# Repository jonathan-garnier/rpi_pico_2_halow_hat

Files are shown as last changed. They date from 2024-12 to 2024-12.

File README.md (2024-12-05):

# HaLow Hat For RPI Pico 2

This repository contains design and output files for a Wi-Fi HaLow hat board for the RPI Pico 2. The board embeds a Morse Micro [MM6108-MF08651-US](https://au.mouser.com/ProductDetail/Morse-Micro/MM6108-MF08651-US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) Wi-Fi HaLow module, as well as a temperature and humidity sensor (SHT40), battery charging circuit, three LEDs, and a QWIIC connector for any other I2C based sensors. Other Wi-Fi HaLow modules with the same form factor will also be compatible, such as the Azurewave [AW-HM593](https://www.azurewave.com/wireless-modules-11ah.html).

## Images
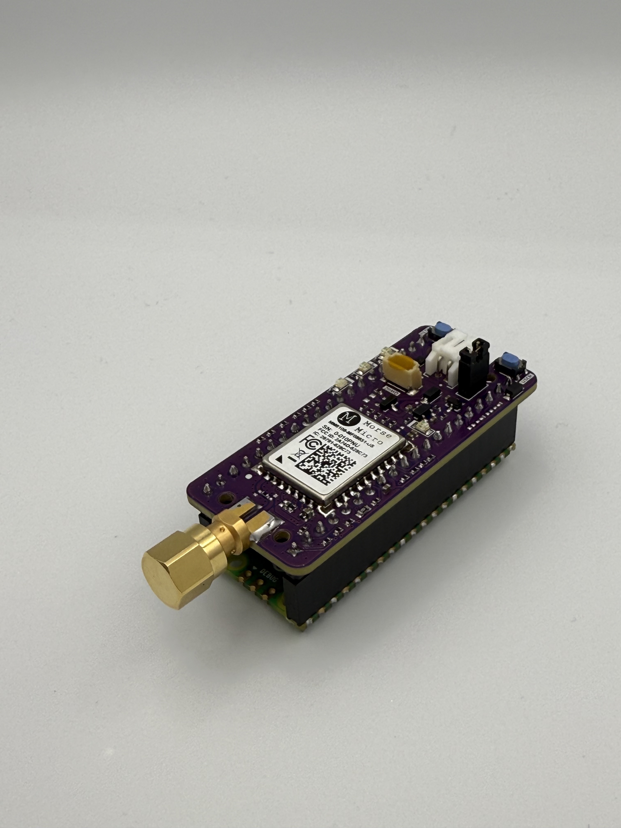
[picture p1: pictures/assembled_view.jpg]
Assembled View

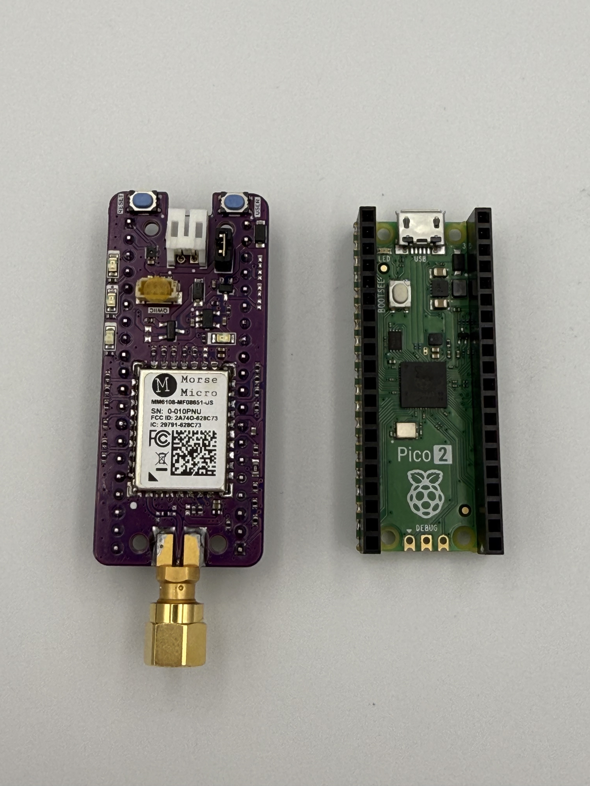
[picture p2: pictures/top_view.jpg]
Top View

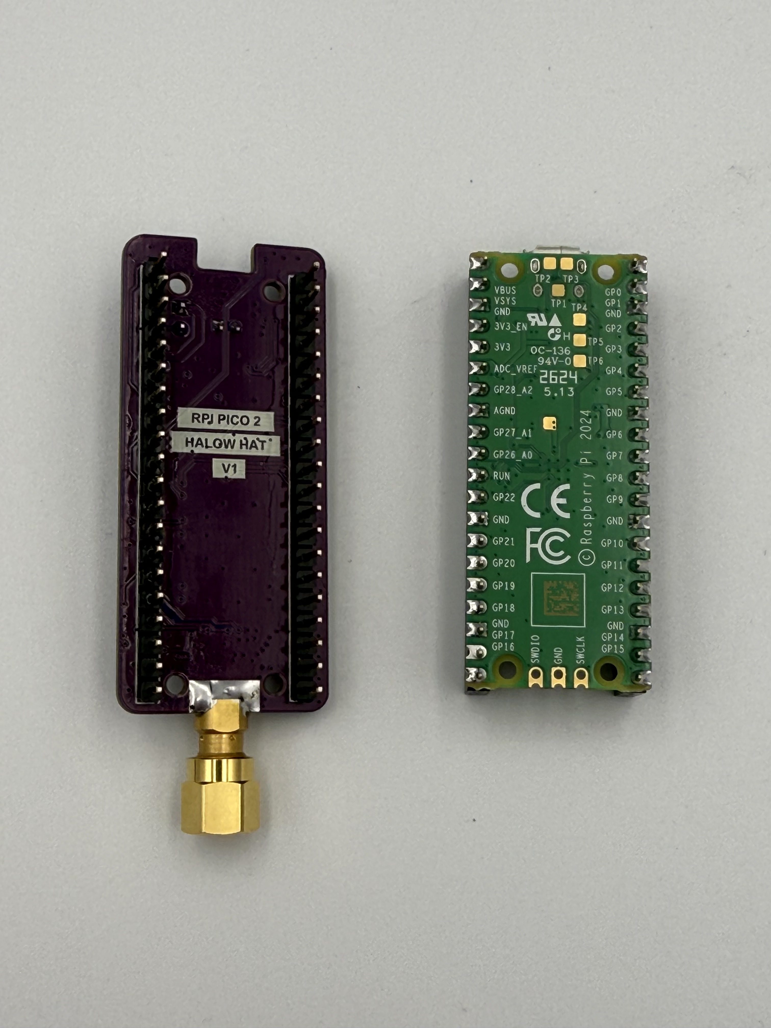
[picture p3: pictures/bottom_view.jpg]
Bottom View

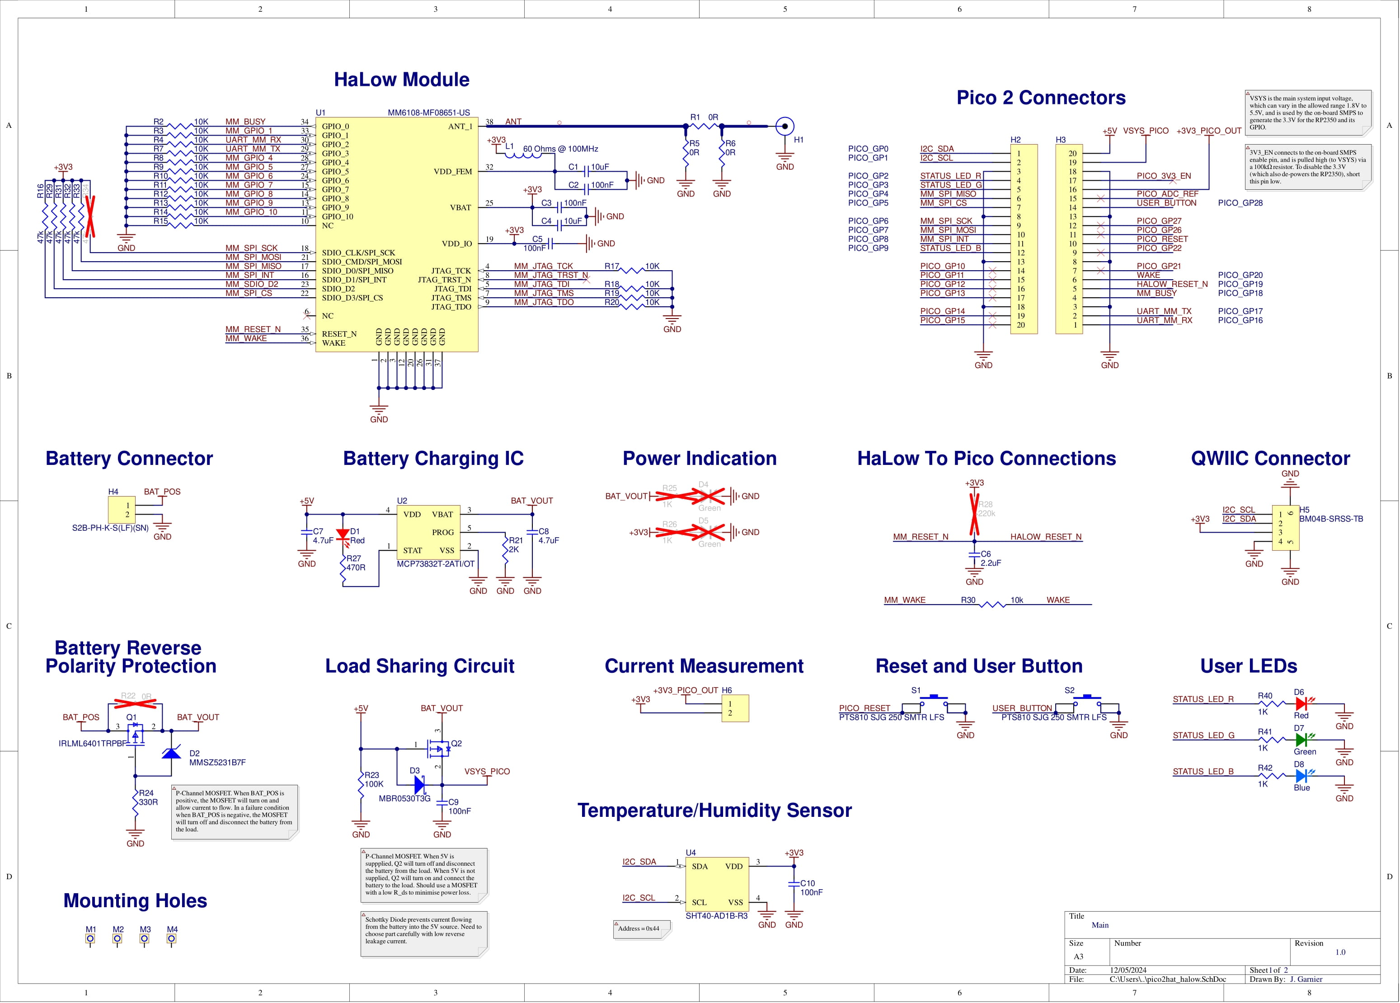
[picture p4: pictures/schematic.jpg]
Schematic


## Fabrication Files
All files needed for fabrication are in the 'Project Outputs for rpi_pico_2_hat' folder. There is a 'Fabrication' folder for gerber and other manufacturing files, and a 'Assembly Default Variant of rpi_pico_2_hat' folder which has pick and place and BOM files.

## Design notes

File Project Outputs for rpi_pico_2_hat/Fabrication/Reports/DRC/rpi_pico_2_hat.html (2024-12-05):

Altium

# Design Rule Verification Report

Date: | | 14/09/2024
Time: | | 8:18:49 AM
Elapsed Time: | | 00:00:01
Filename: | | C:\Users\JonathanGarnier\AppData\Local\Temp\Releases\Snapshot\1\rpi_pico_2_hat.PcbDoc

Warnings: | | 0
Rule Violations: | | 0

## Summary

Warnings | Count
Total | 0

Rule Violations | Count
Clearance Constraint (Gap=6mil) (InDifferentialPair('USBC')),(All) | 0
Clearance Constraint (Gap=10mil) (InNetClass('50 Ohms')),(All) | 0
Clearance Constraint (Gap=10mil) ((InPolygon)),(InNetClass('RF-Net')) | 0
Clearance Constraint (Gap=6mil) (All),(All) | 0
Short-Circuit Constraint (Allowed=No) (All),(All) | 0
Un-Routed Net Constraint ( (All) ) | 0
Un-Connected Pin Constraint ( (Disabled)(All) ) | 0
Modified Polygon (Allow modified: No), (Allow shelved: No) | 0
Width Constraint (Min=4.18mil) (Max=23.622mil) (Preferred=10.236mil) (InDifferentialPair('USBC')) | 0
Width Constraint (Min=8mil) (Max=50mil) (Preferred=8mil) (All) | 0
Width Constraint (Min=4.18mil) (Max=23.622mil) (Preferred=10mil) (InNetClass('50 OHMs')) | 0
Power Plane Connect Rule(Relief Connect )(Expansion=15.748mil) (Conductor Width=10mil) (Air Gap=7.874mil) (Entries=4) ((InComponent('J5') OR InComponent('J6') OR InComponent('J13') OR InComponent('J11') OR InComponent('J12')) OR InComponent('H3')) | 0
Power Plane Connect Rule(Relief Connect )(Expansion=20mil) (Conductor Width=10mil) (Air Gap=10mil) (Entries=4) (All) | 0
Hole Size Constraint (Min=6mil) (Max=200mil) (All) | 0
Hole To Hole Clearance (Gap=8mil) (All),(All) | 0
Minimum Solder Mask Sliver (Gap=1mil) (not InComponent('U4','U1','U5','U6','U7','U8','U9','U10')),(All) | 0
Silk To Solder Mask (Clearance=4mil) (IsPad),(All) | 0
Net Antennae (Tolerance=0mil) (All) | 0
Board Clearance Constraint (Gap=0mil) ((not OnTopSilkscreen) AND (NOT OnBottomSilkscreen) and (not OnMultiLayer) and (not InComponent('H1'))) | 0
Matched Lengths(Tolerance=1000mil) (InNetClass('DCMI')) | 0
Matched Lengths(Tolerance=50mil) (InxSignalClass('xSignals_U1_Passives_J5_MatchLengthsClass')) | 0
Matched Lengths(Tolerance=2000mil) (InNetClass('SDIO')) | 0
Matched Lengths(Tolerance=2000mil) (InNetClass('SDIO_2')) | 0
Matched Lengths(Tolerance=50mil) (InxSignalClass('xSignals_U1_Passives_J5_MatchLengthsClass_1')) | 0
Height Constraint (Min=0mil) (Max=275.591mil) (Prefered=196.85mil) (InComponentClass('POGO')) | 0
Height Constraint (Min=0mil) (Max=472.441mil) (Prefered=118.11mil) (InComponent('TP1')) | 0
Height Constraint (Min=0mil) (Max=1000mil) (Prefered=500mil) (Disabled)(All) | 0
Height Constraint (Min=0mil) (Max=157.48mil) (Prefered=118.11mil) (WithinRoom('ROOM_SOCKET')) | 0
Total | 0

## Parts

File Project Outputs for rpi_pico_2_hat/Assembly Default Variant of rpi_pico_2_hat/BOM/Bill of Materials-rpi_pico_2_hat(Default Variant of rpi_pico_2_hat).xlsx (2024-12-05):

Designator | LibRef | Quantity | Description | Footprint | Manufacturer 1 | Manufacturer Part Number 1 | Supplier 1 | Supplier Part Number 1 | Generic Allowed | Supplier Unit Price 1
H1 | JCK0001-2 | 1 | Conn, SMA Jack 50 Ohm PCB Edge Mount Gold, RoHS | SMA_EMERSON_142_0761_861 | Bel Cinch | 142-0761-861 | Farnell | 2112451 | No | 9.52
U2 | ICT0232-1 | 1 | Power Supply Support Circuit, Adjustable, 1 Channel, PDSO5 | SOT-23-OT5_N | Microchip | MCP73832T-2ATI/OT | Conrad | 1085501 |  | 2.41
U4 | ICT0108-3 | 1 | IC, Humidity Temperature Sensor 0 ~ 100% RH I²C ±1.8% RH 6 s Surface Mount | DFN140P150X59-4N | Sensirion | SHT40-AD1B-R3 | Digikey | 1649-SHT40-AD1B-R3CT-ND | No | 1.21
H5 | HDR0131-2 | 1 | Board Connector, 4 Contact(s), 1 Row(s), Male, Straight, Surface Mount Terminal | FP-BM04B-SRSS-TBT_LF_SN-MFG | JST | BM04B-SRSS-TB | Digikey | 455-BM04B-SRSS-TBCT-ND |  | 0.361
Q1 | TSR0020-1 | 1 | Small Signal Field-Effect Transistor | FP-SOT23-IPC_A | Infineon | IRLML6401TRPBF | Farnell | 1463267 |  | 0.16612
Q2 | TSR0021-1 | 1 | Small Signal Field-Effect Transistor, 1.37A I(D), 20V, 1-Element, P-Channel, Silicon, Metal-oxide Semiconductor FET | FP-419-04-IPC_A | ON Semiconductor | NTS4101PT1G | Farnell | 1453617 |  | 0.16105
D8 | DIO0018-2 | 1 | LED, Blue Clear,3.3V, SMD, 0805, RoHS | LED_0805_BLUE | Vishay Lite-On | LTST-C170TBKT | Digikey | 160-1579-1-ND | Yes | 0.1351
L1 | IND0062-6 | 1 | BEAD 60OHMS 2500MA 32 MOHM | 0402_ind | Murata | BLM15PX600SN1D | Future Electronics | 2105289 | Yes | 0.114
D7 | DIO0015-2 | 1 | LED, Green Clear,2.0V, SMD, 0805, RoHS | LED_0805_GREEN | Vishay Lite-On | LTST-C170KGKT | Digikey | 160-1414-1-ND | Yes | 0.0898
D1, D6 | DIO0016-2 | 2 | LED, Red Clear,2.0V, SMD, 0805, RoHS | LED_0805_RED | Vishay Lite-On | LTST-C170KRKT | Digikey | 160-1415-1-ND | Yes | 0.083
C1, C4 | CAP0046-13 | 2 | CAP CER 10UF 10V 20% X5R 0402 | 0402_cap | Samsung | CL05A106MP8NUB8 | Digikey | 1276-6830-1-ND | Yes | 0.0816
C7, C8 | CAP0075-12 | 2 | CAP CER 4.7UF 6.3V ±10% X5R 0402 | 0402_cap | TDK | C1005X5R0J475K050BC | Newark | 04X3211 | Yes | 0.072
R40, R41, R42 | RES0004-8 | 3 | RES SMD 1K OHM ±1% 1/10W 0402 | RESC1005X04N | Panasonic | ERJ-2RKF1001X | Future Electronics | 2103847 | Yes | 0.0464
D2 | DIO0072-1 | 1 | DIODE ZENER 5.1V 500MW SOD-123 | SOD-123FL | Diodes | MMSZ5231B7F | Newark | 12T2210 |  | 0.046
H4 | HDR0129-2 | 1 | Header for PCB; pitch 2.00mm; 2-contacts; THT; male; side entry; 100V/2A | JST-S2B-PH-K-S_V | JST | S2B-PH-K-S(LF)(SN) | Newark | 38K8066 |  | 0.039
C2, C3, C5, C9, C10 | CAP0068-11 | 5 | CAP CER 100NF 50V ±10% X7R 0402 | 0402_cap | TDK | C1005X7R1H104K050BE | Farnell | 3416071 | Yes | 0.03386
R2, R3, R4, R7, R8, R9, R10, R11, R12, R13, R14, R15, R17, R18, R19, R20 | RES0002-8 | 16 | RES SMD 10K OHM ±1% 1/10W 0402 | RESC1005X04N | Panasonic | ERJ-2RKF1002X | Farnell | 2302739 | Yes | 0.00761
C6 | CAP0086 | 1 | CAP CER 2.2UF 6.3V 20% X5R 0402 | CAPC1005X06N | Taiyo Yuden | JMK105BJ225MVF | Digikey | 587-1453-2-ND | Yes
D3 | DIO0044-2 | 1 | DIODE SCHOTTKY 30V 500MA SOD123 | SOD-123FL | ON Semiconductor | MBR0530T3G | Farnell | 2440968 | Yes
H2, H3 | HDR0128-1 | 2 | 1x20 Female Header | HDR1X20F
H6 | HDR0006-2 | 1 | Conn Straight Header 2x1 0.100" 2 POS | HDR1X2 | Oupiin | 2011-1X02G00SB-1 |  |  | Yes
M1, M2, M3, M4 | PAD0009-2 | 4 | MH NPTH 3.00mm DIA 2.75mm HOLE | MH_300_275_NPTH
R1, R5, R6 | RES0039-10 | 3 | RES SMD 0R OHM ±1% 1/16W 0402 | 0402_res | Yageo | RC0402JR-070RL | Farnell | 2421887 | Yes
R16, R29, R31, R32, R33 | RES0086-8 | 5 | RES SMD 47K OHM ±1% 1/16W 0402 | RESC1005X04N | Yageo | RC0402FR-0747KL | Farnell | 2421898 | Yes
R21 | RES0030-9 | 1 | RES SMD 2K OHM ±1% 1/16W 0402 | 0402_res | Yageo | RC0402FR-072KL | Newark | 12AC2054 | Yes
R23 | RES0023-9 | 1 | RES SMD 100K OHM ±1% 1/16W 0402 | 0402_res | Yageo | RC0402FR-07100KL | Future Electronics | 1122062 | Yes
R24 | RES0025-8 | 1 | RES SMD 330R OHM ±1% 1/16W 0402 | RESC1005X04N | Yageo | RC0402FR-07330RL | Newark | 12AC2074 | Yes
R27 | RES0084-9 | 1 | RES SMD 470R OHM ±1% 1/16W 0402 | 0402_res | Rohm | MCR01MZPF4700 |  |  | Yes
R30 | RES0124 | 1 | Res, 10K Ohm, 1/10W,+/-1%,0603 RoHS | RESC1608X06N | Rohm | MCR03EZPFX1002 | Digi-Key | 311-10.0KHRCT-ND | Yes
S1, S2 | SWH0026-1 | 2 | SWITCH TACTILE SPST-NO 0.05A 16V | SW_PTS810 | ITT C&K | PTS810SJG250SMTRLFS | Newark | 21AH2836 | No
U1 | MOD0010-3 | 1 | MM61xx-MF08 | MF04 | Morse Micro | MM61xx-MF08251

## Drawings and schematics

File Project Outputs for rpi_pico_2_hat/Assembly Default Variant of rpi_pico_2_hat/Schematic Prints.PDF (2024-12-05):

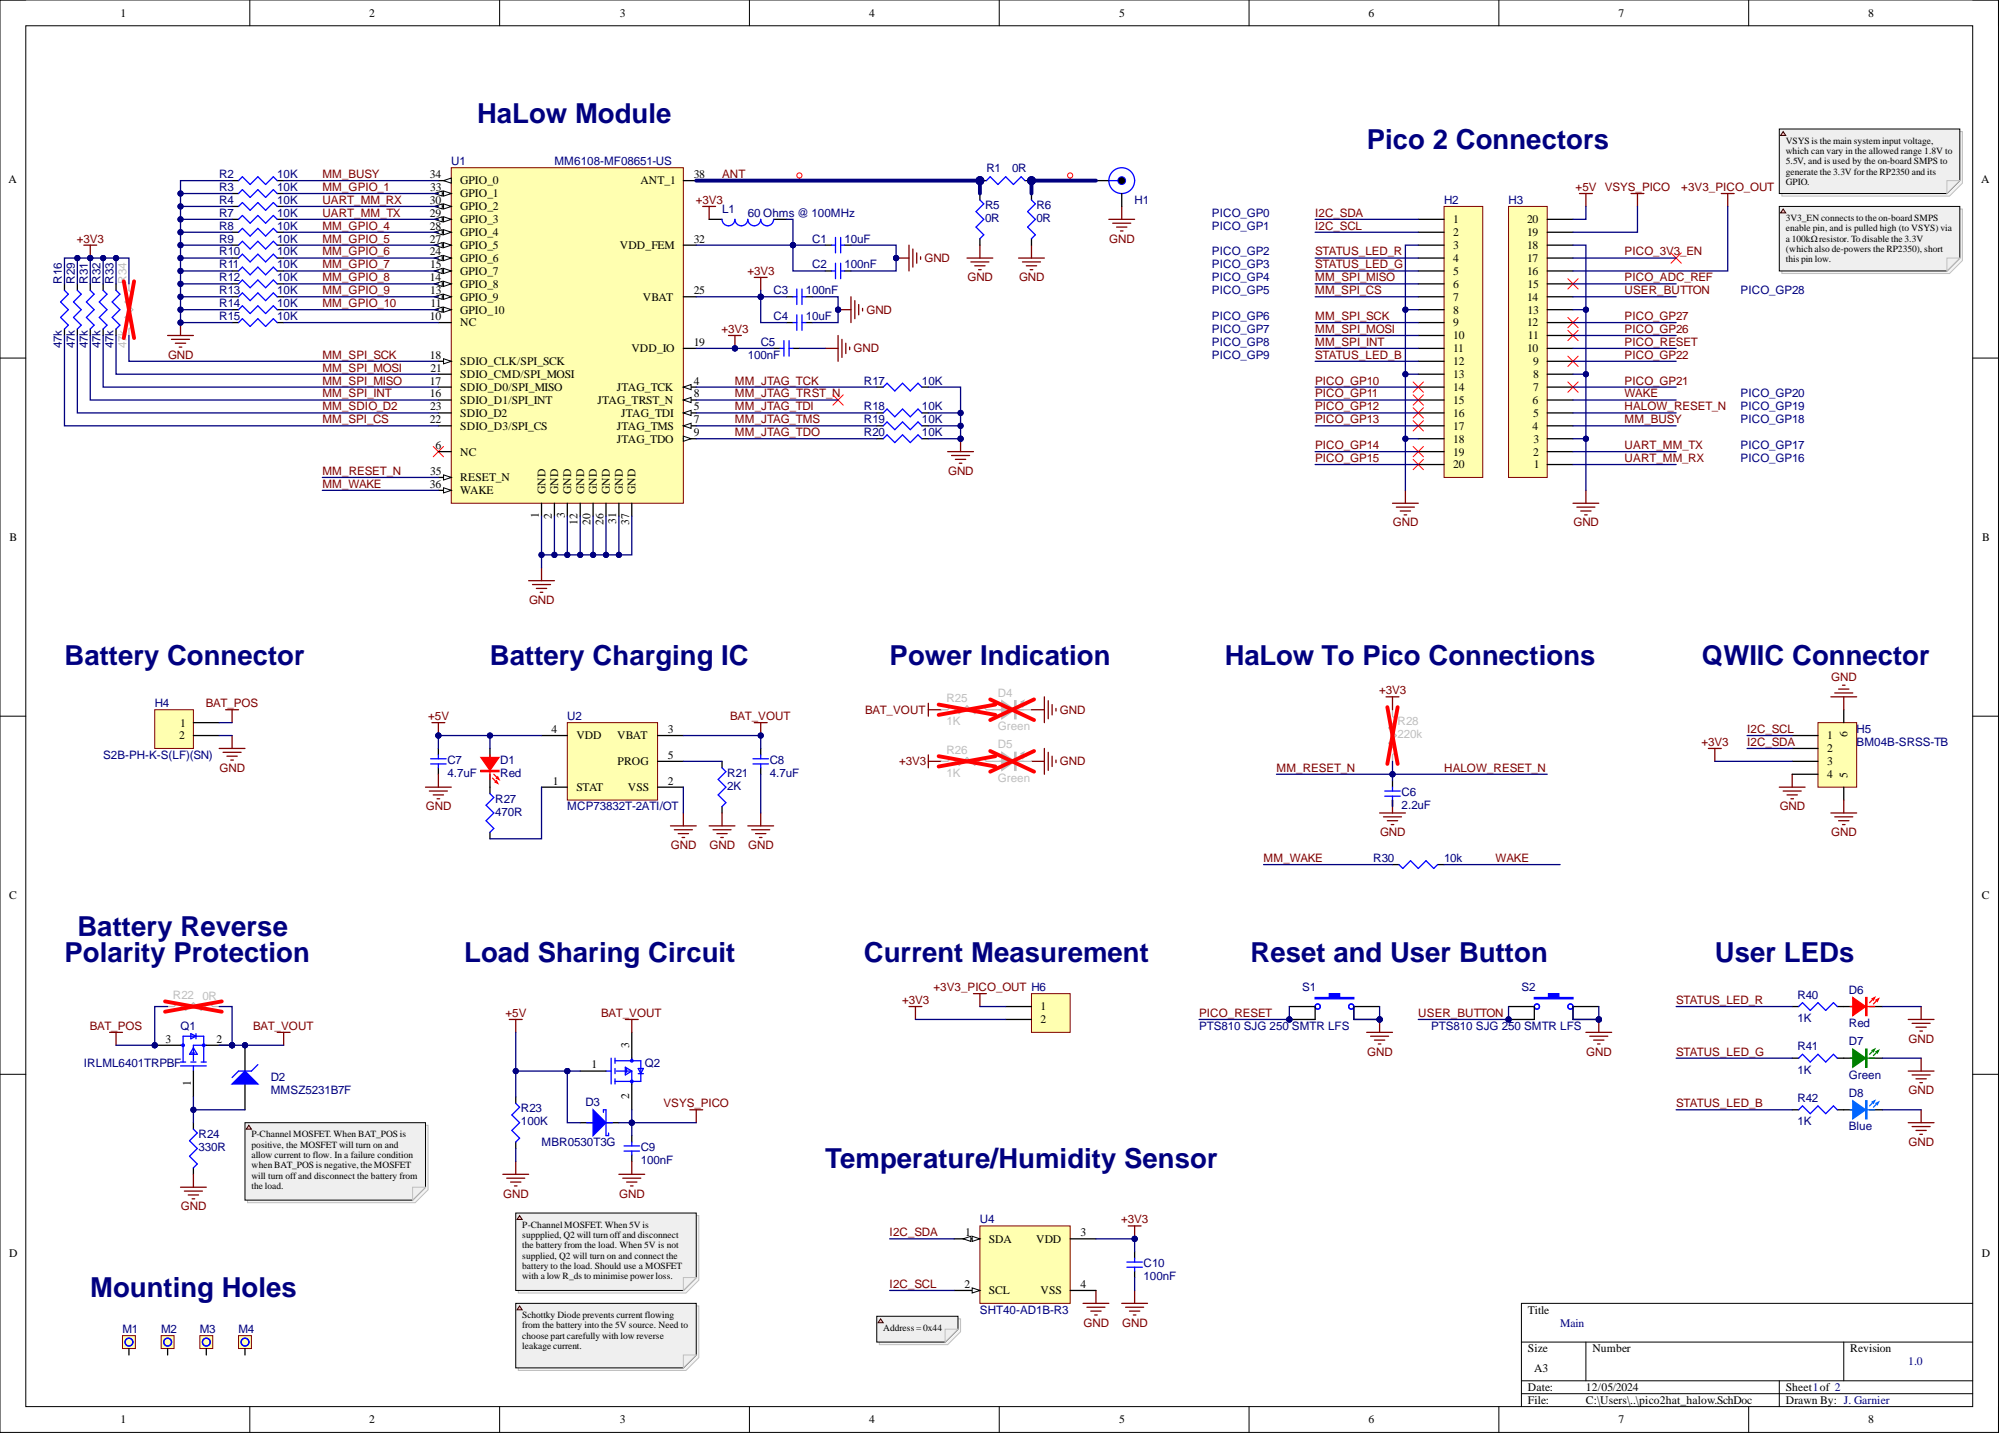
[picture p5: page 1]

VSYS isthe main system input voltage,
which can vary in the allowed range 1.8V to
5.5V, and is used by the on-board SMPS to
generate the 3.3V for the RP2350 and its
GPIO.

R3 | 10K MM_GPIO_1 | GPIO_1 33
R4 | 10K UART_MM_RX | GPIO_2 30

3V3_EN connectsto the on-board SMPS
enable pin, and is pulled high (to VSYS) via
a 100kΩ resistor. To disable the 3.3V
(which also de-powers the RP2350), short
this pin low.

HaLow To Pico Connections

Reset and User Button

P-Channel MOSFET. When BAT_POS is
positive, the MOSFET will turn on and
allow current to flow. In a failure condition
when BAT_POS is negative, the MOSFET
will turn off and disconnect the battery from
the load.

P-Channel MOSFET. When 5V is
suppplied, Q2 will turn off and disconnect
the battery from the load. When 5V is not
supplied, Q2 will turn on and connect the
battery to the load. Should use a MOSFET
with a low R_dsto minimise power loss.

Schottky Diode prevents current flowing
from the battery into the 5V source. Need to
choose part carefully with low reverse
leakage current.

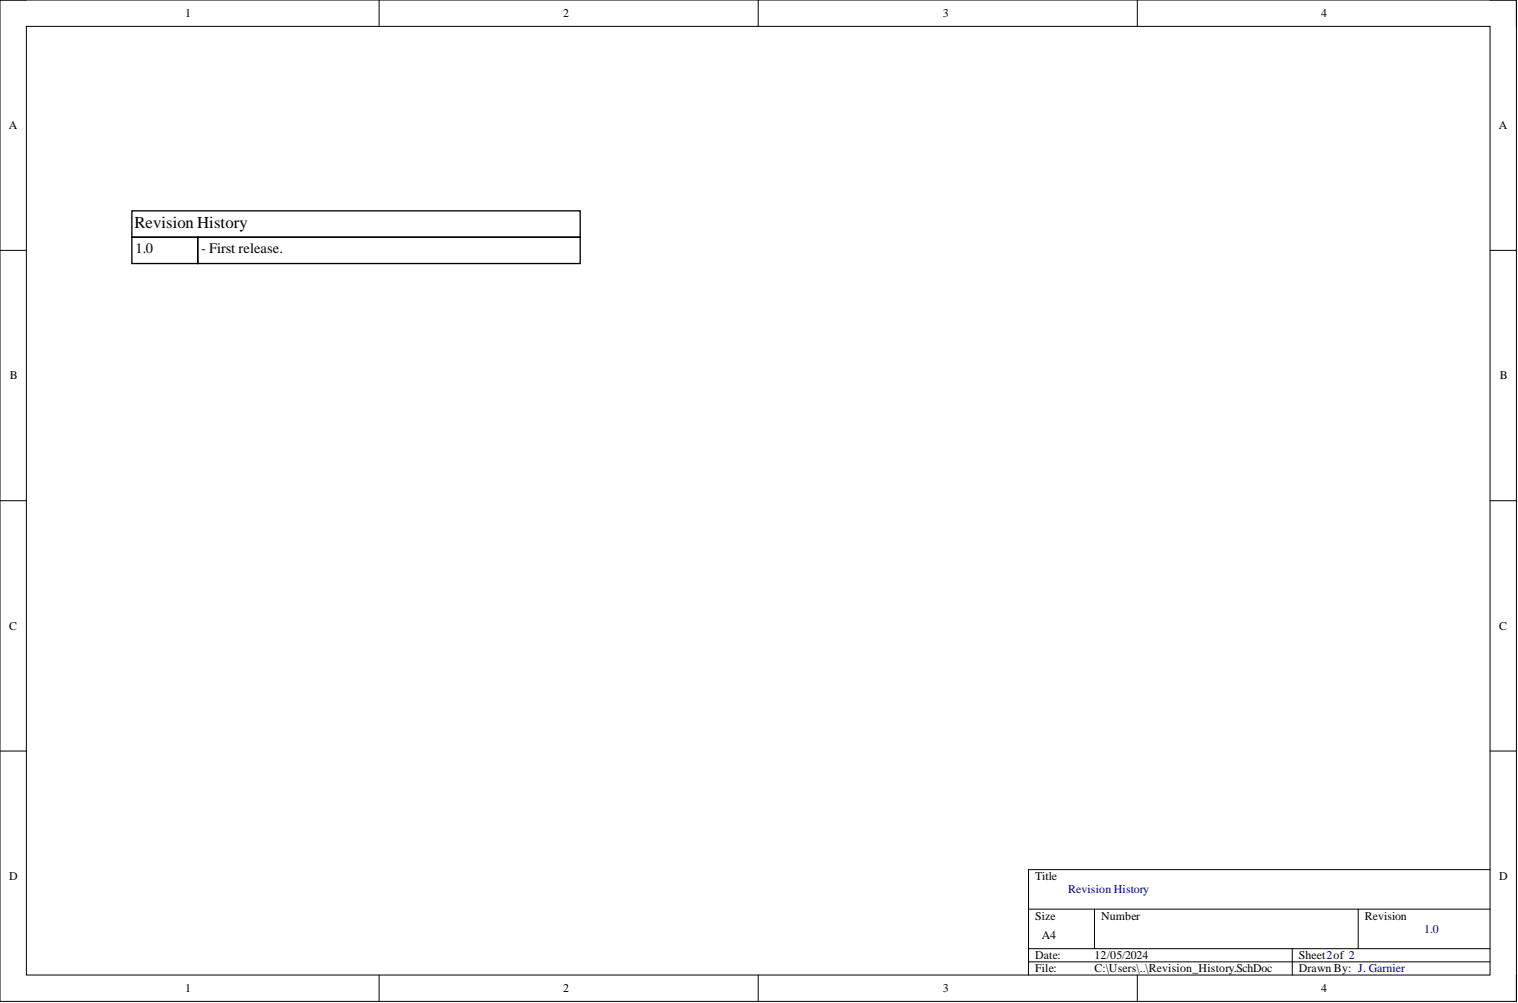
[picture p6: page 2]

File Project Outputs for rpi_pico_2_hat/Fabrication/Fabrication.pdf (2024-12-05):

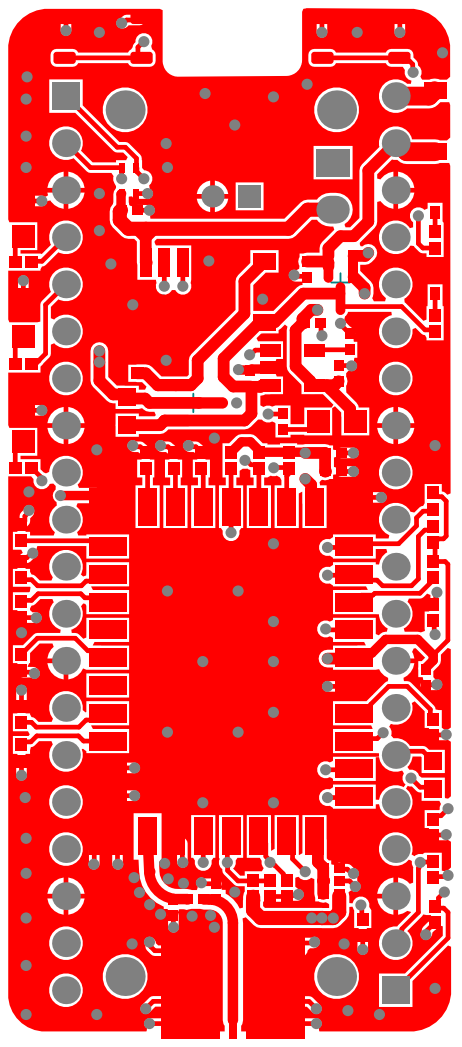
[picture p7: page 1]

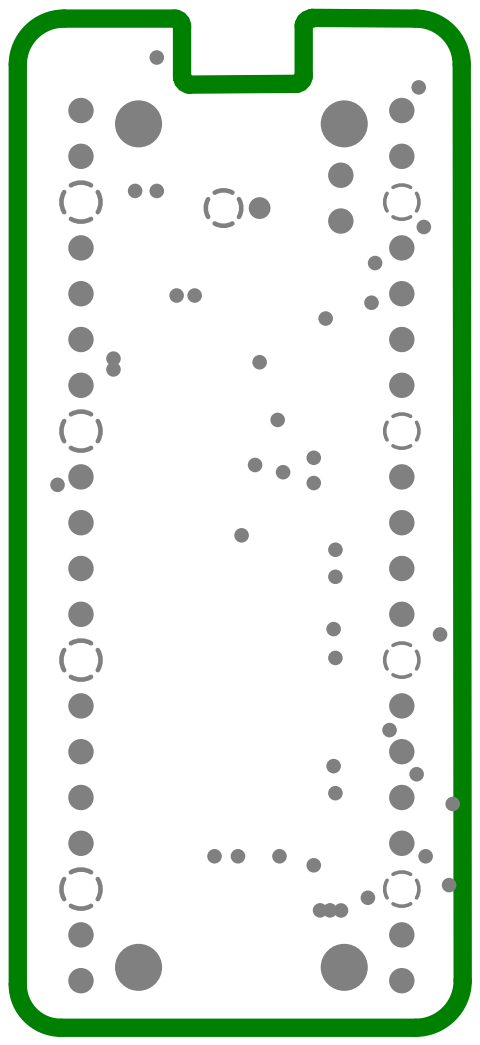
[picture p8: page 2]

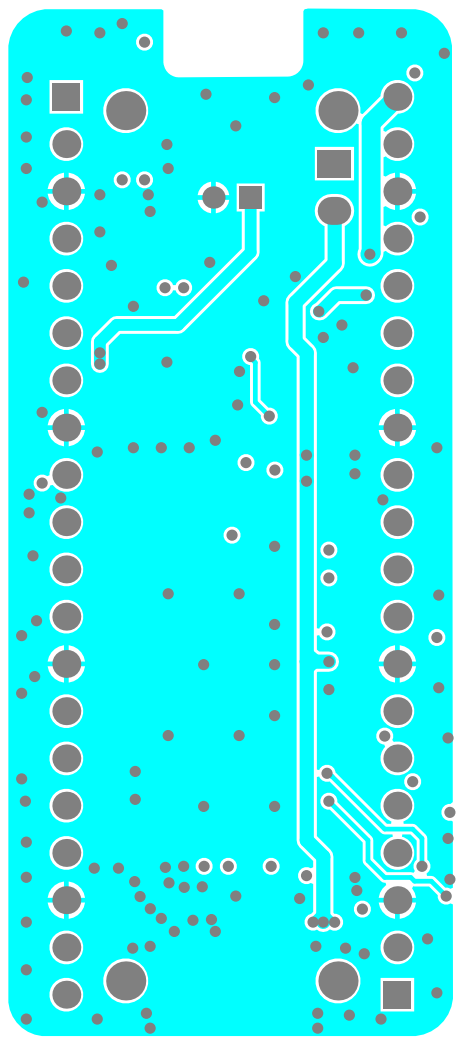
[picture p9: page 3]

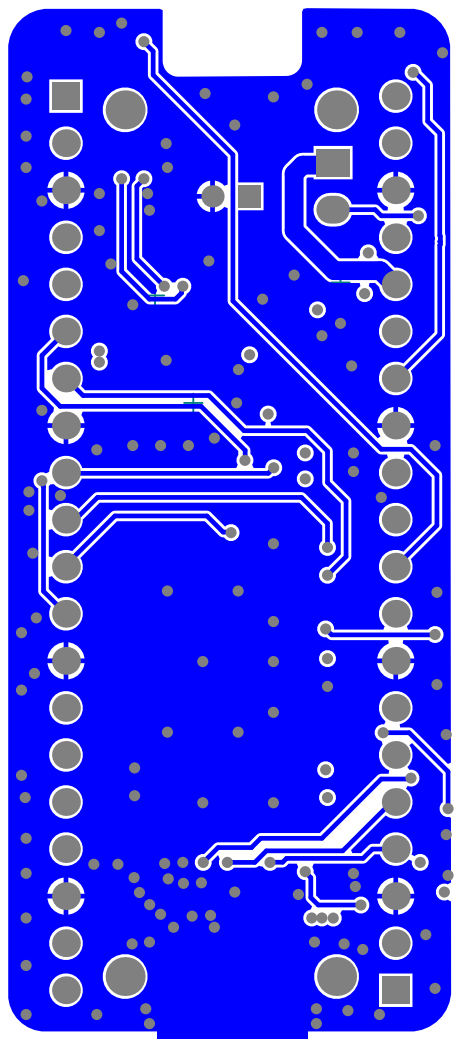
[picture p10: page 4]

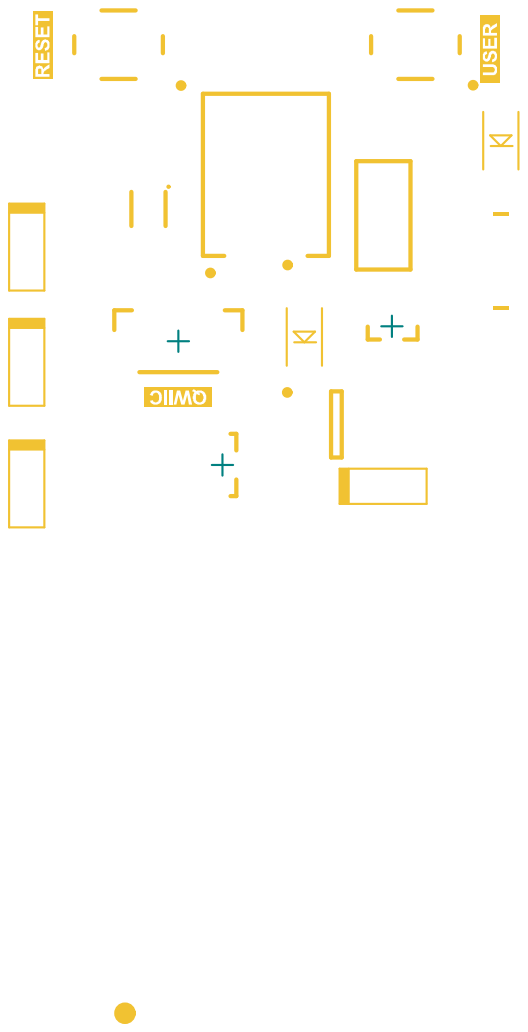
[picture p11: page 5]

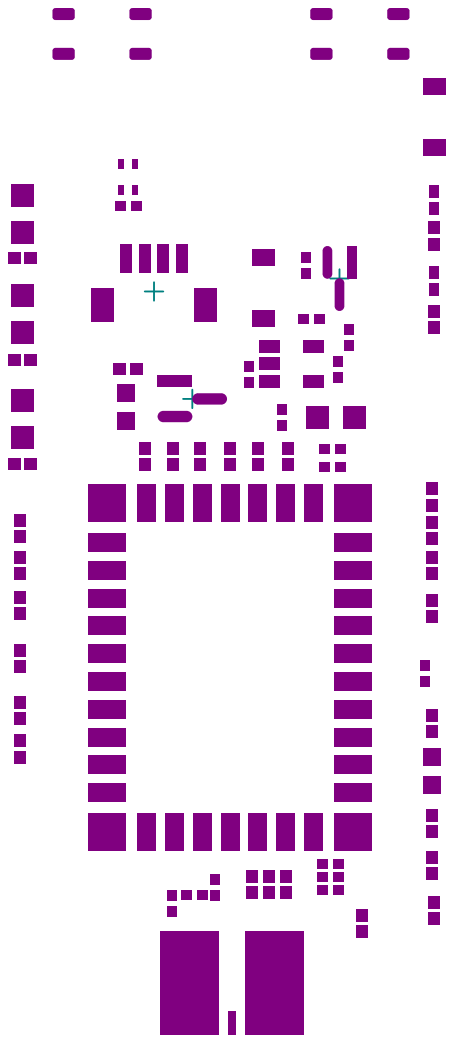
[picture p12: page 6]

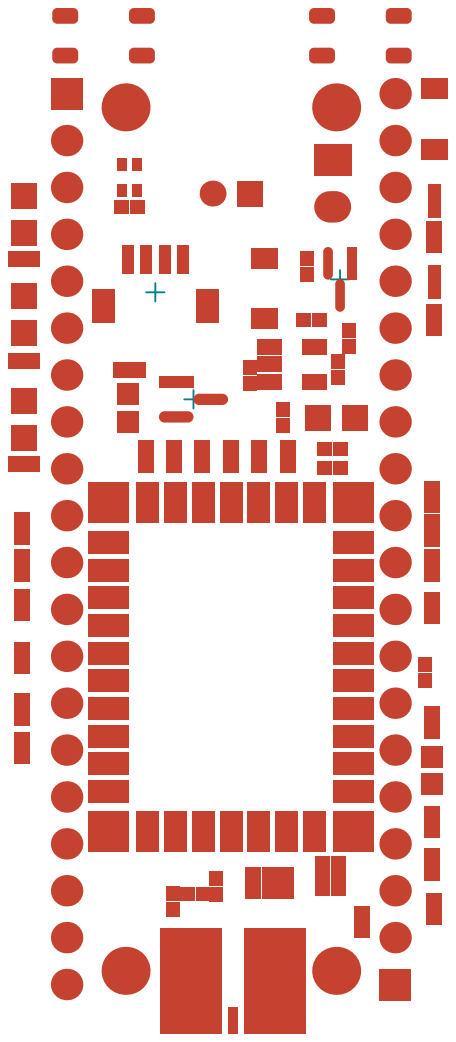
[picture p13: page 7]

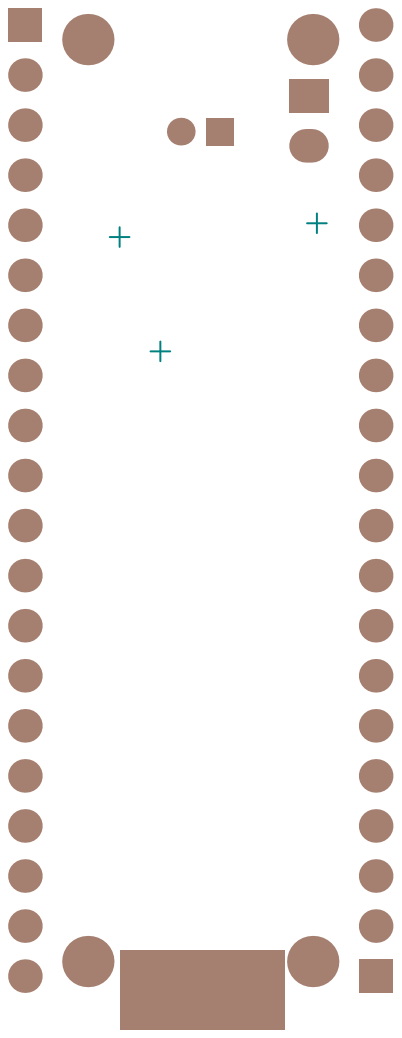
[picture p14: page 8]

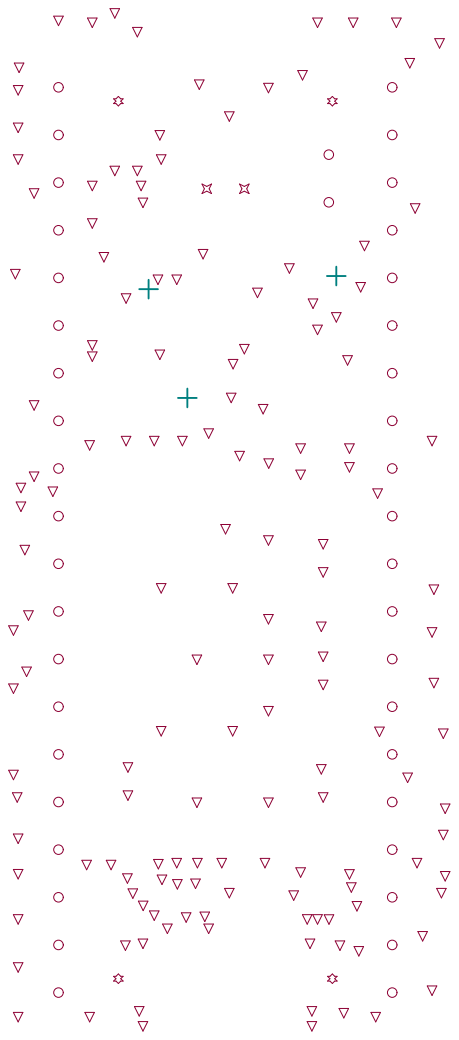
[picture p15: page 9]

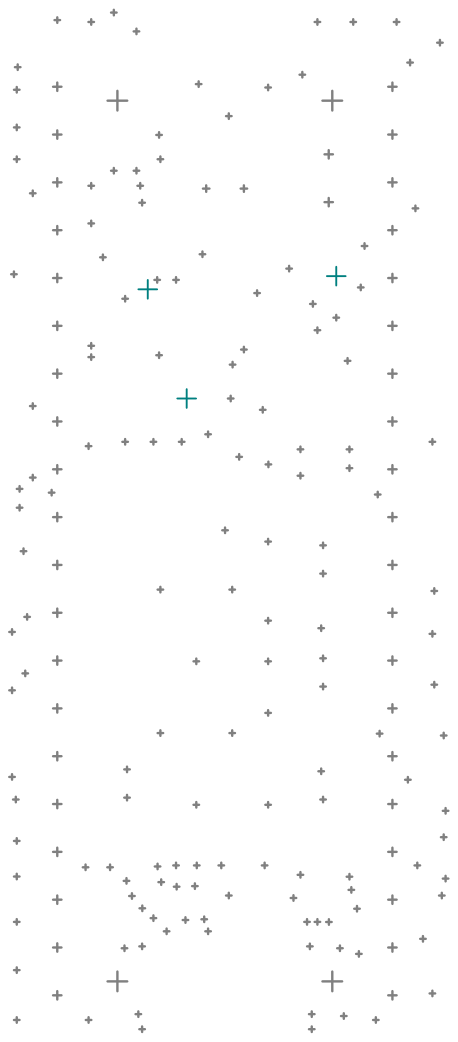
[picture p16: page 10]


Transmission Line Structure Table

Impedance Id | Transmission Line | Target Impedance | Calculated Impedance | Trace layer | Wide Trace Width | Narrow Trace Width | Reference layers | Substack | Clearance | Target Tolerance
1 | Coated Coplanar Waveguide With Ground | 50 | 50.00 | Top Layer | 0.57mm | 0.57mm | Ground Plane | Board Layer Stack | 0.25mm | 5%

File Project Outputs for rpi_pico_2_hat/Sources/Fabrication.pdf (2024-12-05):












Transmission Line Structure Table

Impedance Id | Transmission Line | Target Impedance | Calculated Impedance | Trace layer | Wide Trace Width | Narrow Trace Width | Reference layers | Substack | Clearance | Target Tolerance
1 | Coated Coplanar Waveguide With Ground | 50 | 50.00 | Top Layer | 0.57mm | 0.57mm | Ground Plane | Board Layer Stack | 0.25mm | 5%
